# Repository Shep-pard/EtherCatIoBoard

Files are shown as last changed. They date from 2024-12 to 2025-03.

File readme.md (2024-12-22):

# Simple EtherCat IO Board

This repo contains software and hardware for a simple Ethercat IO Board to be used with linuxcnc.
It features 48 Inputs, 48 Outputs, 4 Encoder inputs (that could be used as outputs, but the softare currently doesn't support this) and 6 Analog inputs. 
The Outputs are 0,5A high side switches. And the IOs can either run on 5V or 24V (the input voltage of the board). Just change the jumper on the board. 

The project is based on:
- SOES: https://github.com/OpenEtherCATsociety/SOES
- This example implementation https://github.com/kubabuda/ecat_servo

I used the https://github.com/kubabuda/EEPROM_generator to generated my ESI files.
Thanks to those creators, you made my life very easy! 

###  License
Don't violate the original licenses. Use how you please.
No gurantees that it isn't error free. :)

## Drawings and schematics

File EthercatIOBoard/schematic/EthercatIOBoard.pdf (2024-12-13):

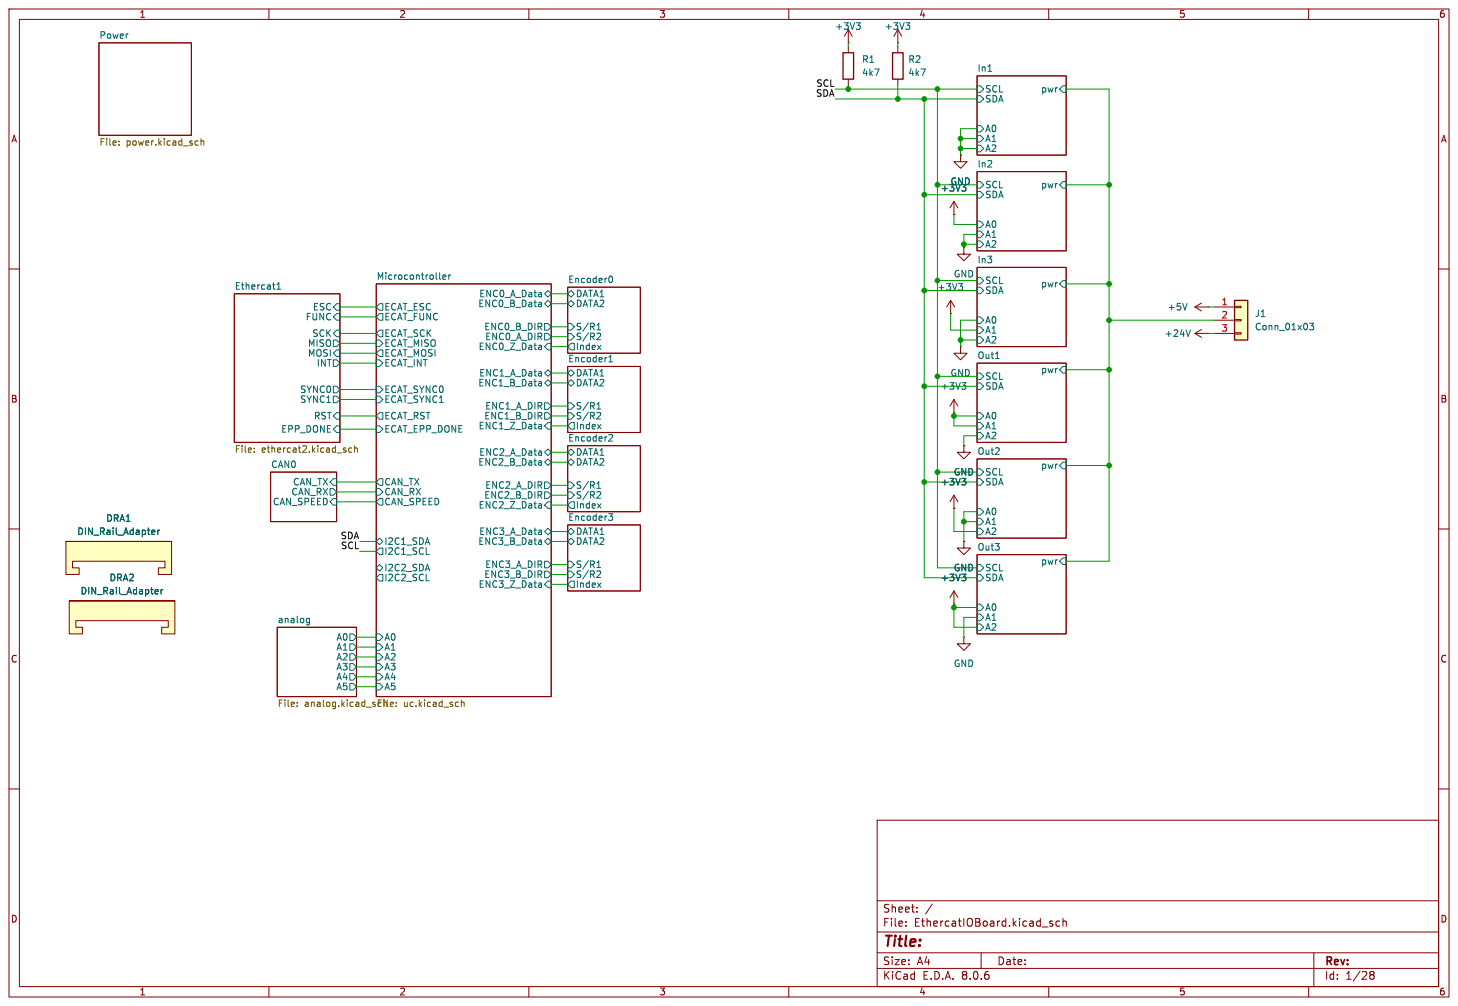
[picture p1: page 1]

Id: 1/28 Title: File: EthercatIOBoard.kicad_sch Sheet: / A0A1A2A5A3A4

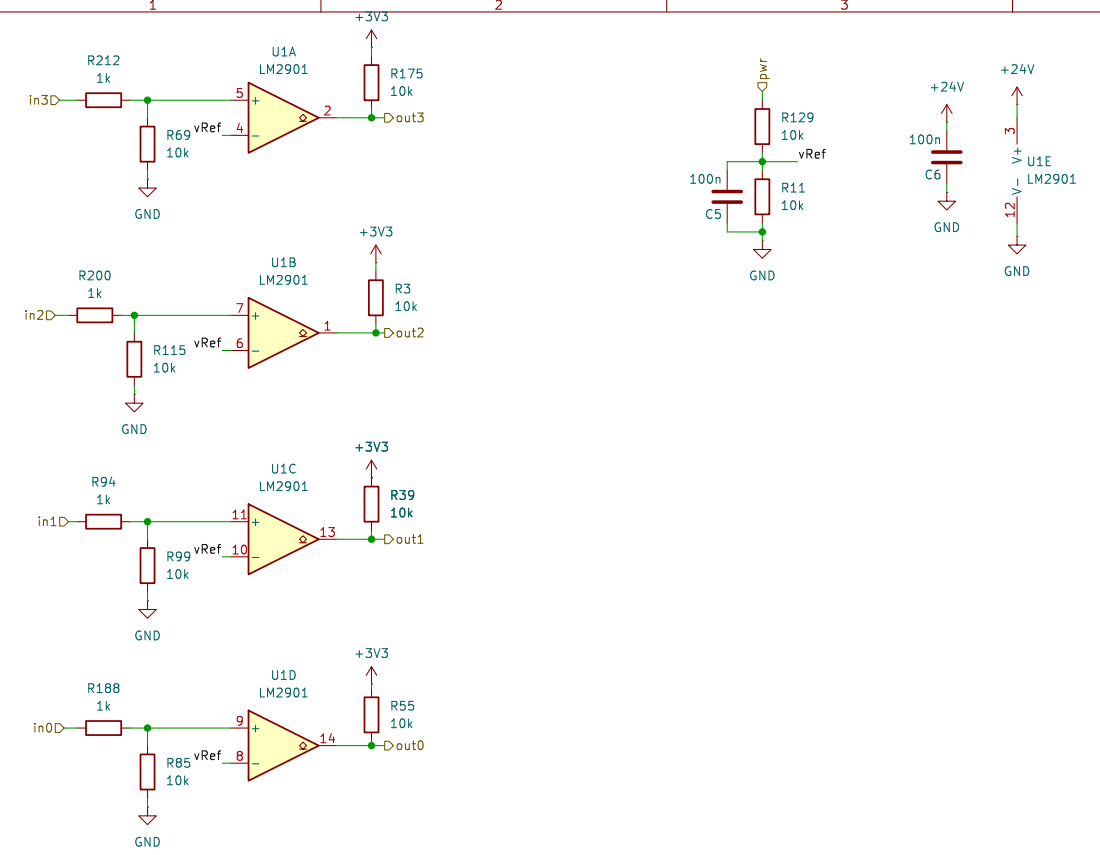
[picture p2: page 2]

Id: 2/28 Title: File: digInSingle.kicad_sch Sheet: /In1/in0/

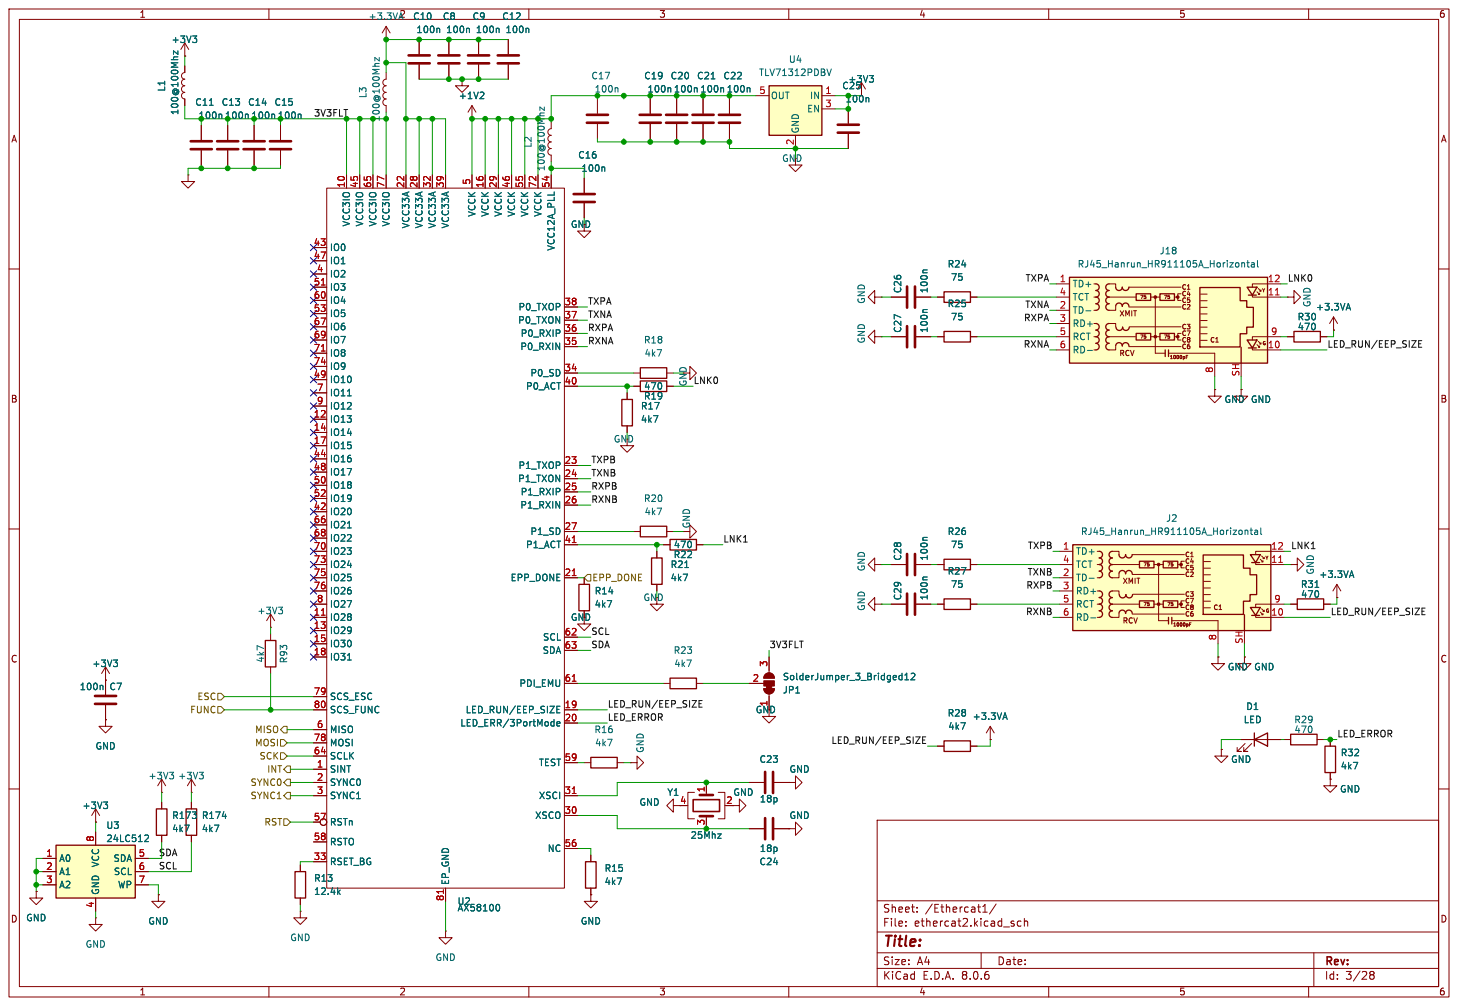
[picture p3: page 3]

12 TD- 2 RD+ 3 TCT 4 RCT 5 RD- 6

ESC
INT RST SYNC1 SCK MISO

4 SDA 5 SCL 6 WP 7 VCC

Id: 3/28 Title: File: ethercat2.kicad_sch Sheet: /Ethercat1/ R15
4k7 GND

Id: 3/28 Title: File: uc.kicad_sch Sheet: /Microcontroller/

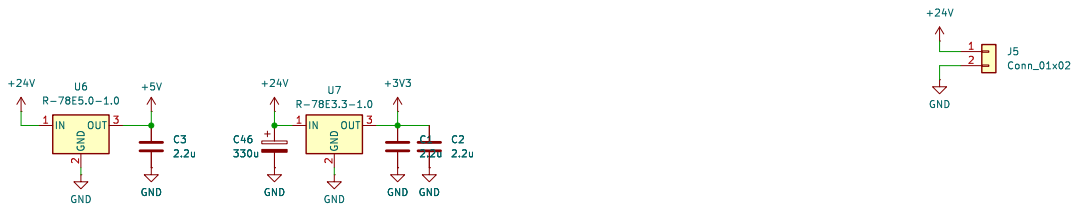
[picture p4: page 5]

Id: 4/28 Title: File: power.kicad_sch Sheet: /Power/

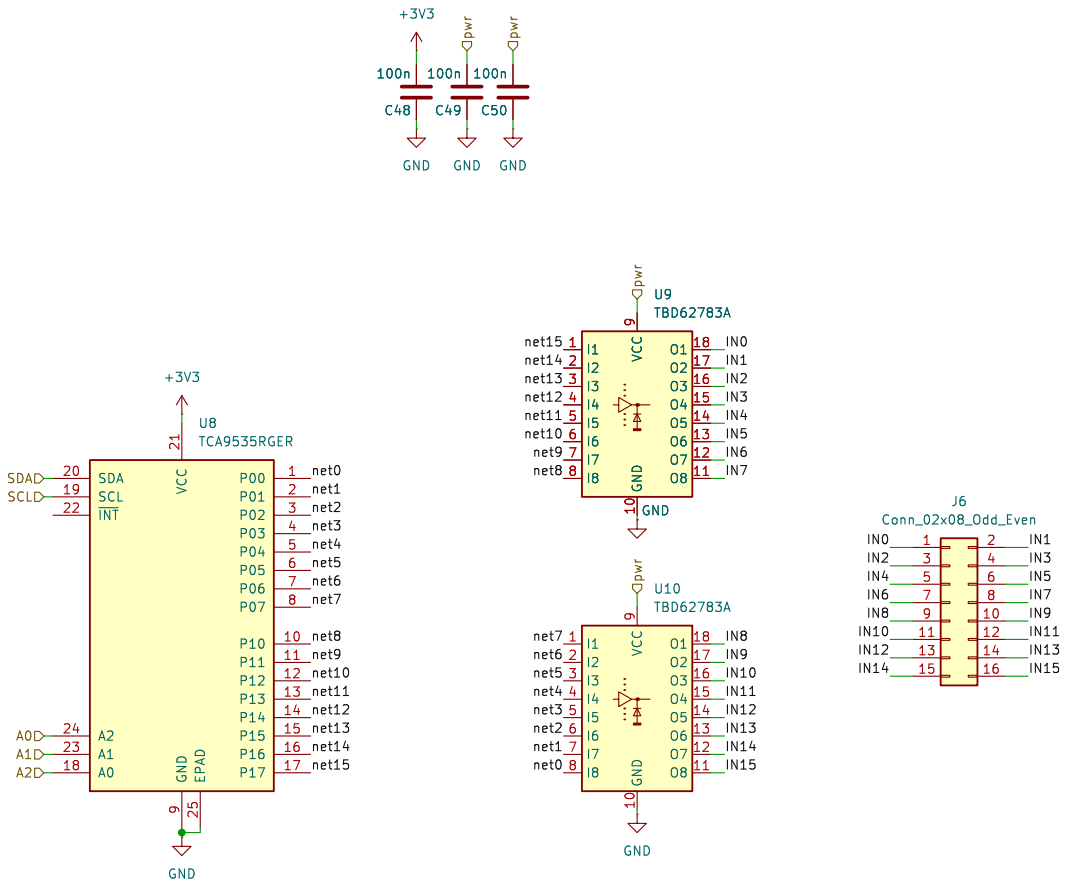
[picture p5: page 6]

Id: 5/28 Title: File: digOut.kicad_sch Sheet: /Out1/ GND

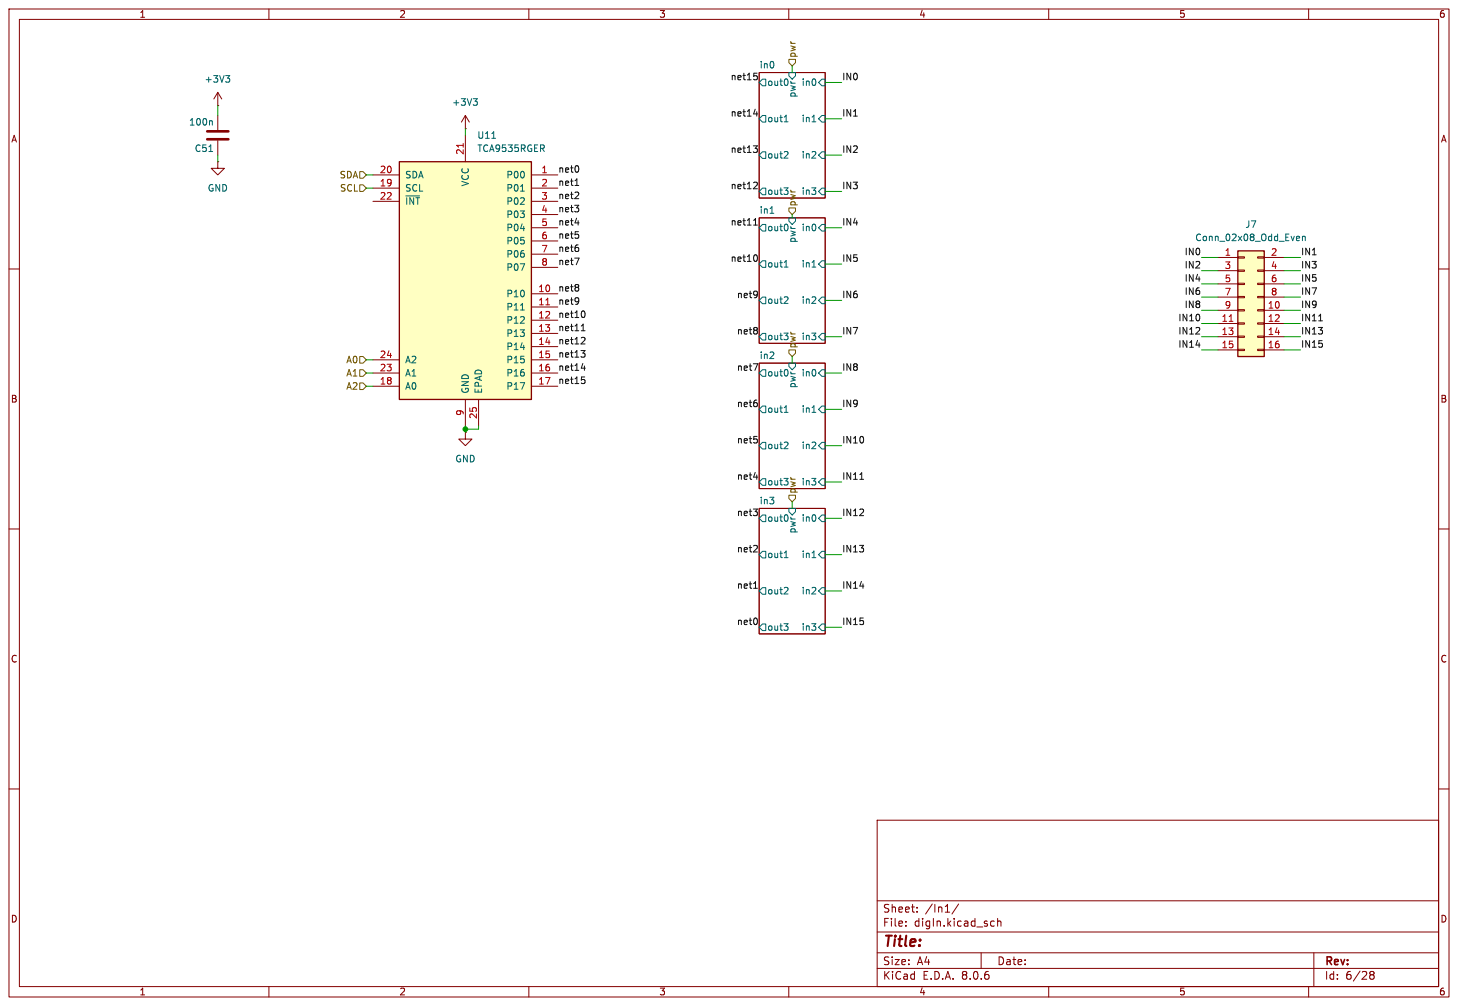
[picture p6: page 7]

Id: 6/28 Title: File: digIn.kicad_sch Sheet: /In1/

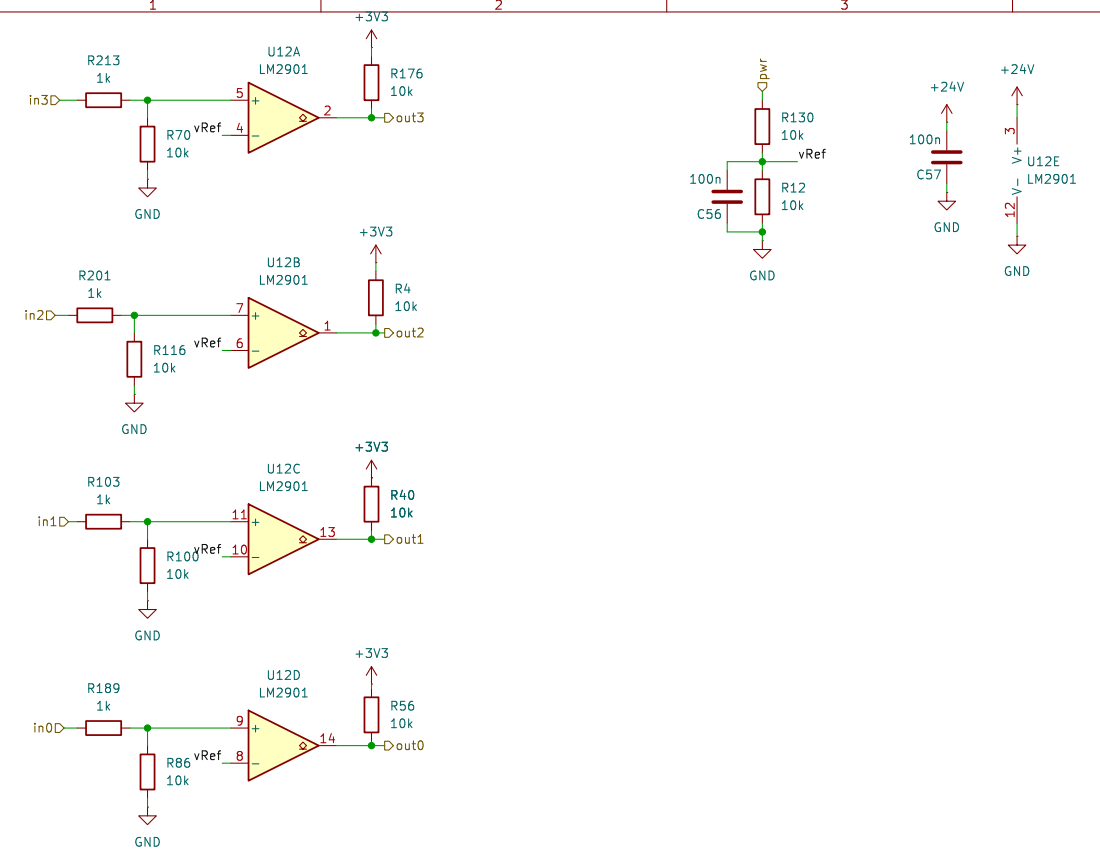
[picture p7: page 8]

Id: 7/28 Title: File: digInSingle.kicad_sch Sheet: /In1/in1/ V- 12 V+ 3 U12E

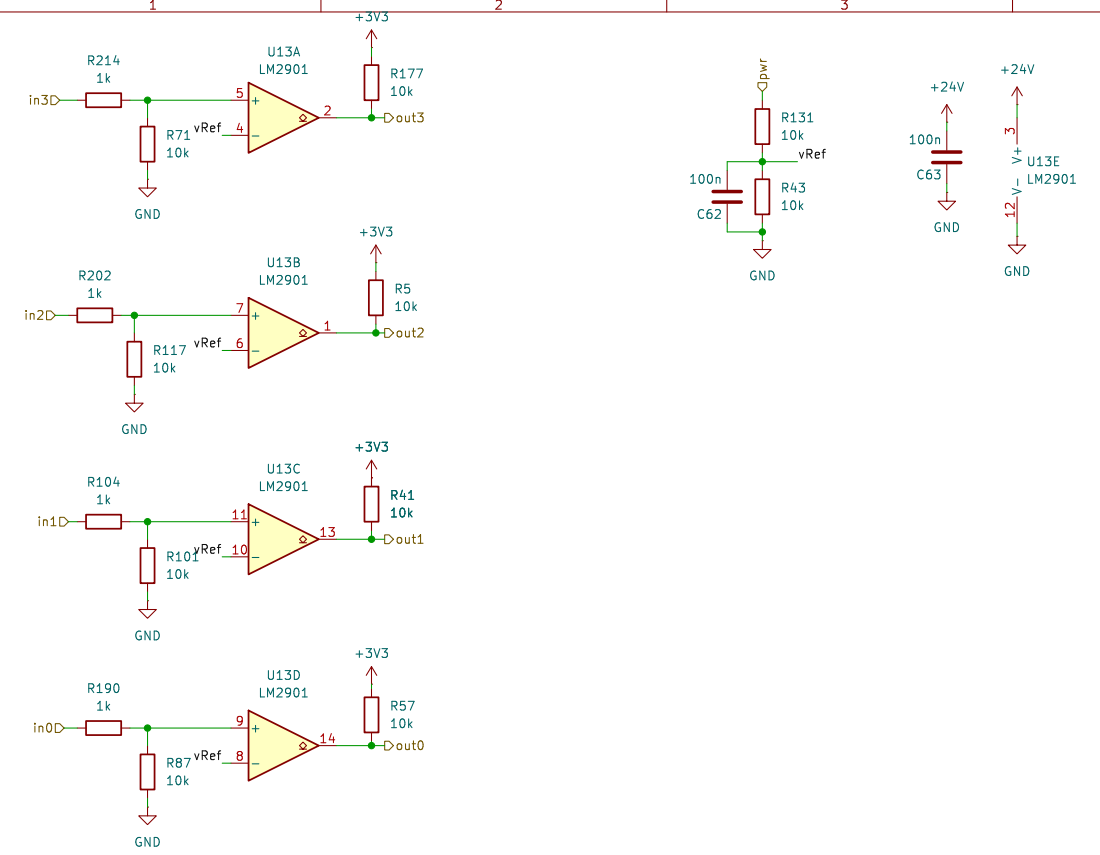
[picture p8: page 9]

Id: 8/28 Title: File: digInSingle.kicad_sch Sheet: /In2/in1/

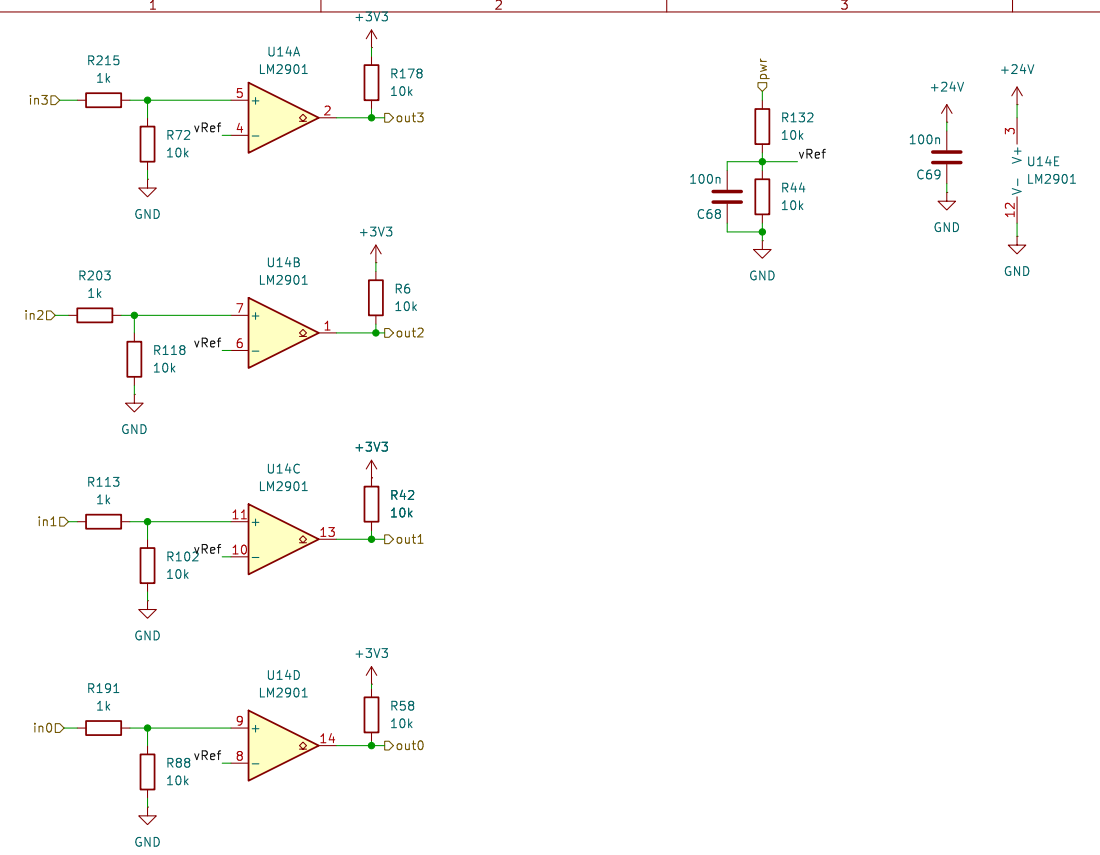
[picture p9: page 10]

Id: 9/28 Title: File: digInSingle.kicad_sch Sheet: /In3/in1/ V- 12 V+ 3 U14E

Id: 10/28 Title: File: digInSingle.kicad_sch Sheet: /In1/in2/

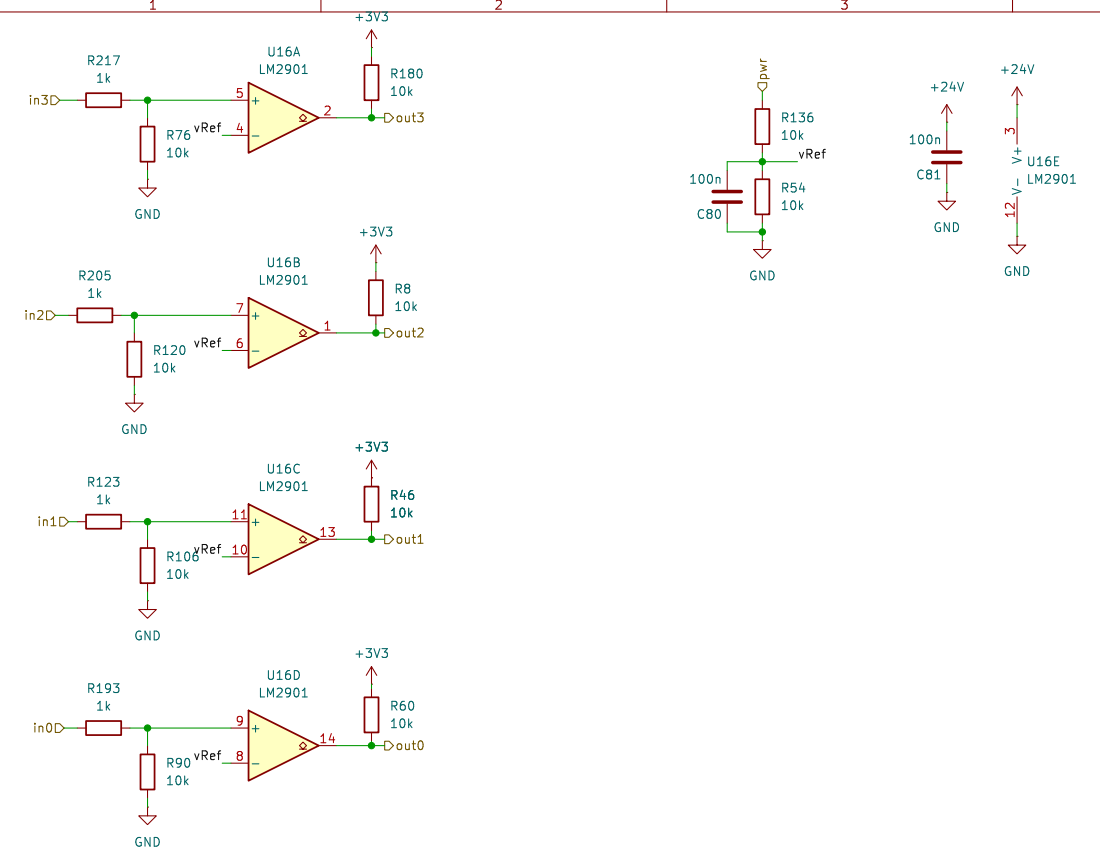
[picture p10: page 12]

Id: 11/28 Title: File: digInSingle.kicad_sch Sheet: /In2/in2/ V- 12 V+ 3 U16E

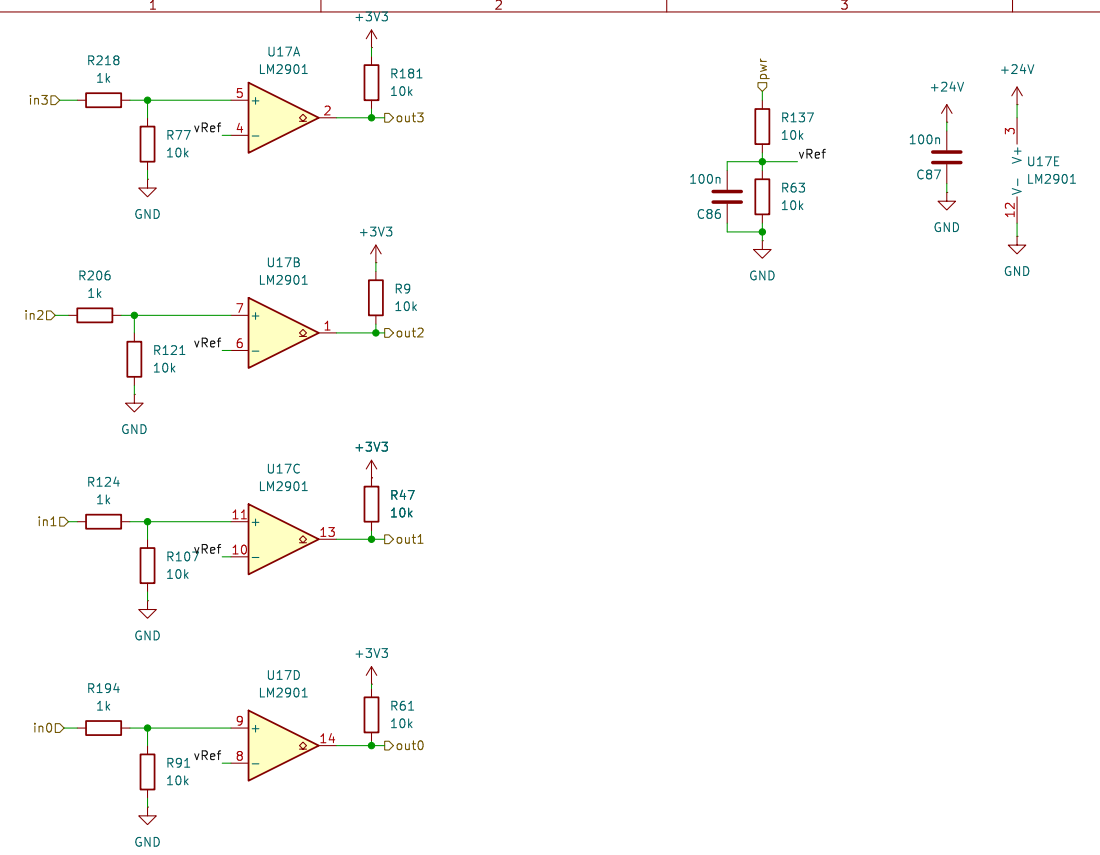
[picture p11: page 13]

Id: 12/28 Title: File: digInSingle.kicad_sch Sheet: /In3/in2/

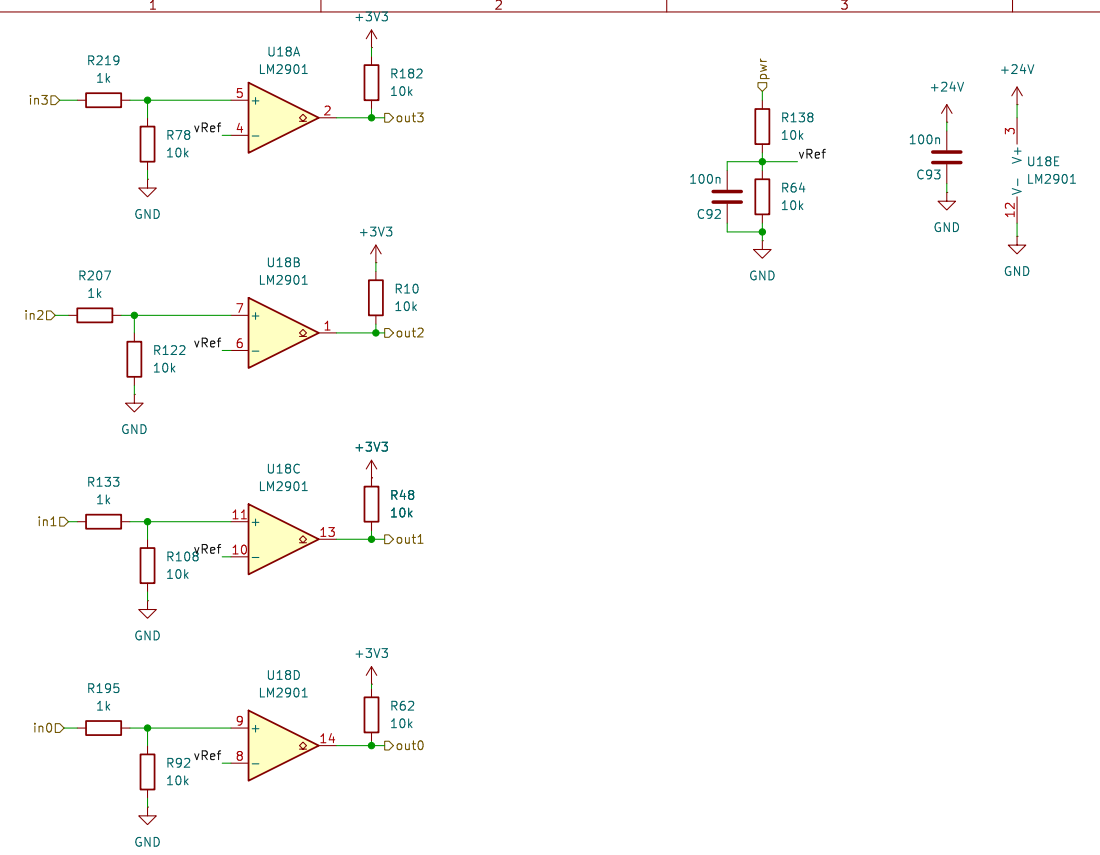
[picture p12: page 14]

Id: 13/28 Title: File: digInSingle.kicad_sch Sheet: /In1/in3/ V- 12 V+ 3 U18E


Id: 14/28 Title: File: digIn.kicad_sch Sheet: /In2/


Id: 15/28 Title: File: digInSingle.kicad_sch Sheet: /In2/in0/


Id: 16/28 Title: File: digInSingle.kicad_sch Sheet: /In2/in3/ V- 12 V+ 3 U21E

Id: 17/28 Title: File: digInSingle.kicad_sch Sheet: /In3/in3/


Id: 23/28 Title: File: digIn.kicad_sch Sheet: /In3/


Id: 24/28 Title: File: digInSingle.kicad_sch Sheet: /In3/in0/ V- 12 V+ 3 U24E


Id: 50/28 Title: File: digOut.kicad_sch Sheet: /Out2/ GND


Id: 51/28 Title: File: digOut.kicad_sch Sheet: /Out3/ GND


Id: 58/28 Title: File: encoderIn.kicad_sch Sheet: /Encoder1/ R147


Id: 59/28 Title: File: encoderIn.kicad_sch Sheet: /Encoder2/ R151

Id: 60/28 Title: File: encoderIn.kicad_sch Sheet: /Encoder3/ R155


Id: 63/28 Title: File: can.kicad_sch Sheet: /CAN0/


5 5 | 6 6

Id: 64/28 Title: File: analog.kicad_sch Sheet: /analog/


Id: 65/28 Title: File: encoderIn.kicad_sch Sheet: /Encoder0/ R171

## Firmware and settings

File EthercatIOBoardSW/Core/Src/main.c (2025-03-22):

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
/* Includes ------------------------------------------------------------------*/
#include "main.h"

/* USER CODE BEGIN Includes */
#include "ecat_slv.h"
#include "utypes.h"
#include "esc.h"
#include "stdbool.h"
#include <string.h>
/* USER CODE END Includes */

/* USER CODE BEGIN PM */
#define INPUT_REG     0x00
#define OUTPUT_REG    0x02
#define POLARITY_REG  0x04
#define DIRECTION_REG 0x06
/* USER CODE END PM */

ADC_HandleTypeDef hadc1;
DMA_HandleTypeDef hdma_adc1;

FDCAN_HandleTypeDef hfdcan2;

I2C_HandleTypeDef hi2c1;

IWDG_HandleTypeDef hiwdg1;

SPI_HandleTypeDef hspi1;

TIM_HandleTypeDef htim1;
TIM_HandleTypeDef htim2;
TIM_HandleTypeDef htim3;
TIM_HandleTypeDef htim4;
TIM_HandleTypeDef htim16;
TIM_HandleTypeDef htim17;

/* USER CODE BEGIN PV */

_Objects Obj; // Ethercat data


void disableAllOutputs();
void stateChangeHook(uint8_t* applicationState, uint8_t* applicationError);

static esc_cfg_t config =
    {
        .user_arg = NULL,
        .use_interrupt = 0,
        .watchdog_cnt = 150,
        .set_defaults_hook = NULL,
        .pre_state_change_hook = NULL,
        .post_state_change_hook = stateChangeHook,
        .application_hook = NULL,
        .safeoutput_override = disableAllOutputs,
        .pre_object_download_hook = NULL,
        .post_object_download_hook = NULL,
        .rxpdo_override = NULL,
        .txpdo_override = NULL,
        .esc_hw_interrupt_enable = NULL,
        .esc_hw_interrupt_disable = NULL,
        .esc_hw_eep_handler = NULL,
        .esc_check_dc_handler = NULL,
};

// IO VARS:
uint8_t inputExpanders[]  = {0x20<<1, 0x24<<1, 0x22<<1};
uint16_t inputData[3];

uint8_t outputExpanders[] = {0x25<<1, 0x21<<1, 0x26<<1};
uint16_t outputData[3] = {0};
uint16_t newOutputData[3] = {0};

// ADC VARS:
uint16_t adcVal[6];

int32_t encoderValues[4];




// STATE VARS:
volatile bool isInOp = false;
volatile bool updateEthercat = false;


const uint32_t timeout = 200;

/* USER CODE END PV */

void SystemClock_Config(void);
static void MX_GPIO_Init(void);
static void MX_DMA_Init(void);
static void MX_FDCAN2_Init(void);
static void MX_SPI1_Init(void);
static void MX_TIM1_Init(void);
static void MX_TIM2_Init(void);
static void MX_TIM3_Init(void);
static void MX_TIM4_Init(void);
static void MX_I2C1_Init(void);
static void MX_ADC1_Init(void);
static void MX_IWDG1_Init(void);
static void MX_TIM16_Init(void);
static void MX_TIM17_Init(void);
/**
  * @brief  The application entry point.
  * @retval int
  */
int main(void)
{

  /* MCU Configuration--------------------------------------------------------*/

  /* Reset of all peripherals, Initializes the Flash interface and the Systick. */
  HAL_Init();

  /* Configure the system clock */
  SystemClock_Config();

  /* Initialize all configured peripherals */
  MX_GPIO_Init();
  MX_DMA_Init();
  MX_FDCAN2_Init();
  MX_SPI1_Init();
  MX_TIM1_Init();
  MX_TIM2_Init();
  MX_TIM3_Init();
  MX_TIM4_Init();
  MX_I2C1_Init();
  MX_ADC1_Init();
  MX_IWDG1_Init();
  MX_TIM16_Init();
  MX_TIM17_Init();
  /* USER CODE BEGIN 2 */
  ecat_slv_init(&config);

  // Start the encoders
  HAL_TIM_Encoder_Start(&htim1, TIM_CHANNEL_ALL);
  HAL_TIM_Encoder_Start(&htim2, TIM_CHANNEL_ALL);
  HAL_TIM_Encoder_Start(&htim3, TIM_CHANNEL_ALL);
  HAL_TIM_Encoder_Start(&htim4, TIM_CHANNEL_ALL);

  // update ethercat data with 10kHz
  HAL_TIM_Base_Start_IT(&htim16);


  // configure the IO Expanders as in/outputs
  uint8_t allOnes[]  = {0xFF, 0xFF};
  uint8_t allZeros[] = {0x00, 0x00};
  for(uint8_t i = 0; i < 3; i++)
  {
	  // can't write 4 regs at once. not sure why
	  HAL_I2C_Mem_Write(&hi2c1, inputExpanders[i], DIRECTION_REG, 1, allOnes, 2, 100);
	  HAL_I2C_Mem_Write(&hi2c1, inputExpanders[i], POLARITY_REG, 1, allZeros, 2, 100);

	  HAL_I2C_Mem_Write(&hi2c1, outputExpanders[i], OUTPUT_REG, 1, allZeros, 2, 100);
	  HAL_I2C_Mem_Write(&hi2c1, outputExpanders[i], POLARITY_REG, 1, allZeros, 2, 100);
	  HAL_I2C_Mem_Write(&hi2c1, outputExpanders[i], DIRECTION_REG, 1, allZeros, 2, 100);

  }


  HAL_ADC_Start_IT(&hadc1);

  /* USER CODE END 2 */

  /* Infinite loop */
  /* USER CODE BEGIN WHILE */
  while (1)
  {

// needed when using sync. But for IOs sync is really not needed.
//	  uint64_t dTime;
//	 if (serveIRQ)
//	 {
//		DIG_process(DIG_PROCESS_WD_FLAG | DIG_PROCESS_OUTPUTS_FLAG |
//					DIG_PROCESS_APP_HOOK_FLAG | DIG_PROCESS_INPUTS_FLAG);
//		serveIRQ = 0;
//		ESCvar.PrevTime = ESCvar.Time;
//		ecat_slv_poll();
//


	  if (updateEthercat)
	  {
		HAL_IWDG_Refresh(&hiwdg1);
		ecat_slv();
		updateEthercat = false;
		 for(uint8_t i = 0; i < 3; i++)
		 {
			 HAL_I2C_Mem_Read(&hi2c1, inputExpanders[i], INPUT_REG, 1, (uint8_t*)&inputData[i], 2, 100);
			 if(newOutputData[i] != outputData[i] && isInOp)
			 {
				 HAL_I2C_Mem_Write(&hi2c1, outputExpanders[i], OUTPUT_REG, 1, (uint8_t*)&newOutputData[i], 2, 100);
				 outputData[i] = newOutputData[i];
			 }
		 }
	  }

    /* USER CODE END WHILE */

    /* USER CODE BEGIN 3 */
  }
  /* USER CODE END 3 */
}

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
/* USER CODE BEGIN 4 */




void disableAllOutputs()
{
	memset(outputData, 0x00, sizeof(outputData));
	for(uint8_t i = 0; i < 3; i++)
	{
		HAL_I2C_Mem_Write(&hi2c1, outputExpanders[i], OUTPUT_REG, 1, (uint8_t*)&outputData[i], 2, 100);
	}
	isInOp = false;
}
void stateChangeHook(uint8_t* oldState, uint8_t* newState)
{
	if(*newState == ESCop)
	{
		isInOp = true;
	}

}


void cb_set_outputs(void) // Get Master outputs, slave inputs, first operation
{
	for(uint8_t i = 0; i < 3; i++)
	{
		newOutputData[i] = __RBIT(Obj.Outputs[i]) >> 16;
	}
}

void cb_get_inputs(void) // Set Master inputs, slave outputs, last operation
{
	for(uint8_t i = 0; i < 3; i++)
	{
		Obj.Inputs[i] = __RBIT(inputData[i]) >> 16;
	}

	for(uint8_t i = 0; i< 6; i++)
	{
		Obj.Analog[i] = adcVal[i];
	}
	// TODO: linuxcnc wants s32 values. Need to convert the values correctly. tim1/3/4 are only 16bit cnt registers. Need to keep track over the overlap manually.
  for (uint8_t i = 0; i < 4; i++)
    {
    Obj.Encoder[i] = encoderValues[i];
    }
}



/* USER CODE END 4 */
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


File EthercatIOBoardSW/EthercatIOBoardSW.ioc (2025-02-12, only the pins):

Mcu.UserName=STM32H743VITx
PA0.Signal=ADC1_INP16
PA1.Signal=S_TIM2_CH2
PA2.Signal=ADCx_INP14
PA3.Signal=ADCx_INP15
PA4.GPIO_Label=SPI_CS
PA4.Signal=GPIO_Output
PA5.Signal=SPI1_SCK
PA6.Signal=SPI1_MISO
PA7.Signal=SPI1_MOSI
PB0.Signal=ADCx_INP9
PB12.Signal=FDCAN2_RX
PB13.Signal=FDCAN2_TX
PB15.GPIO_Label=ESC_GPIO_Pin_RSTN
PB15.Signal=GPIO_Output
PB6.Signal=I2C1_SCL
PB7.Signal=I2C1_SDA
PC1.Signal=ADCx_INP11
PC5.Signal=ADCx_INP8
PC6.Signal=S_TIM3_CH1
PC7.Signal=S_TIM3_CH2
PD0.GPIO_Label=ENC1_Z_Data
PD0.Signal=GPXTI0
PD1.GPIO_Label=ENC2_Z_Data
PD1.Signal=GPXTI1
PD10.GPIO_Label=ENC3_B_DIR
PD10.Signal=GPIO_Output
PD11.GPIO_Label=ENC4_B_DIR
PD11.Signal=GPIO_Output
PD12.Signal=S_TIM4_CH1
PD13.Signal=S_TIM4_CH2
PD2.GPIO_Label=ENC3_Z_Data
PD2.Signal=GPXTI2
PD3.GPIO_Label=ENC4_Z_Data
PD3.Signal=GPXTI3
PD4.GPIO_Label=ENC1_A_DIR
PD4.Signal=GPIO_Output
PD5.GPIO_Label=ENC2_A_DIR
PD5.Signal=GPIO_Output
PD6.GPIO_Label=ENC3_A_DIR
PD6.Signal=GPIO_Output
PD7.GPIO_Label=ENC4_A_DIR
PD7.Signal=GPIO_Output
PD8.GPIO_Label=ENC1_B_DIR
PD8.Signal=GPIO_Output
PD9.GPIO_Label=ENC2_B_DIR
PD9.Signal=GPIO_Output
PE11.Signal=S_TIM1_CH2
PE9.Signal=S_TIM1_CH1

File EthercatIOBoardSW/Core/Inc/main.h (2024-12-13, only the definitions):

#define SPI_CS_Pin GPIO_PIN_4
#define SPI_CS_GPIO_Port GPIOA
#define ESC_GPIO_Pin_RSTN_Pin GPIO_PIN_15
#define ESC_GPIO_Pin_RSTN_GPIO_Port GPIOB
#define ENC1_B_DIR_Pin GPIO_PIN_8
#define ENC1_B_DIR_GPIO_Port GPIOD
#define ENC2_B_DIR_Pin GPIO_PIN_9
#define ENC2_B_DIR_GPIO_Port GPIOD
#define ENC3_B_DIR_Pin GPIO_PIN_10
#define ENC3_B_DIR_GPIO_Port GPIOD
#define ENC4_B_DIR_Pin GPIO_PIN_11
#define ENC4_B_DIR_GPIO_Port GPIOD
#define ENC1_Z_Data_Pin GPIO_PIN_0
#define ENC1_Z_Data_GPIO_Port GPIOD
#define ENC1_Z_Data_EXTI_IRQn EXTI0_IRQn
#define ENC2_Z_Data_Pin GPIO_PIN_1
#define ENC2_Z_Data_GPIO_Port GPIOD
#define ENC2_Z_Data_EXTI_IRQn EXTI1_IRQn
#define ENC3_Z_Data_Pin GPIO_PIN_2
#define ENC3_Z_Data_GPIO_Port GPIOD
#define ENC3_Z_Data_EXTI_IRQn EXTI2_IRQn
#define ENC4_Z_Data_Pin GPIO_PIN_3
#define ENC4_Z_Data_GPIO_Port GPIOD
#define ENC4_Z_Data_EXTI_IRQn EXTI3_IRQn
#define ENC1_A_DIR_Pin GPIO_PIN_4
#define ENC1_A_DIR_GPIO_Port GPIOD
#define ENC2_A_DIR_Pin GPIO_PIN_5
#define ENC2_A_DIR_GPIO_Port GPIOD
#define ENC3_A_DIR_Pin GPIO_PIN_6
#define ENC3_A_DIR_GPIO_Port GPIOD
#define ENC4_A_DIR_Pin GPIO_PIN_7
#define ENC4_A_DIR_GPIO_Port GPIOD

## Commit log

2024-12-13 inital commit
    [EthercatIOBoard.kicad_sch, analog.kicad_sch, can.kicad_sch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]
2024-12-14 small improvments
    [encoderIn.kicad_sch]
2024-12-15 some cleanup
    [EthercatIOBoard.kicad_sch, ethercat2.kicad_sch]
2024-12-22 added some fixes to the pcb
    [EthercatIOBoard.kicad_sch]
2025-02-12 changed encoders to s32 values for linuxcnc
2025-03-22 convert encoder to int32 for linuxcnc

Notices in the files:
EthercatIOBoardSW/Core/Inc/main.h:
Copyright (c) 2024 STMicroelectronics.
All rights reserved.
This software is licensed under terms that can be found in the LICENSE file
